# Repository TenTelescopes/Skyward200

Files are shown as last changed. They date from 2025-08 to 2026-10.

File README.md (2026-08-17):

# Skyward200

These designs are licensed under the [Creative Commons Attribution–NonCommercial 4.0 International License](https://creativecommons.org/licenses/by-nc/4.0/).

You are free to:
- Download, modify, and use for personal, non-commercial purposes.
- Share adaptations with credit to **Ten Telescopes**.

You may **not**:
- Sell these designs.
- Sell physical products made from these designs without written permission.

For commercial inquiries, contact: admin@tentelescopes.com

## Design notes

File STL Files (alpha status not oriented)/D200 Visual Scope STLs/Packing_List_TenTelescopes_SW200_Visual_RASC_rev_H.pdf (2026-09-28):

## Ten Telescopes – Skyward 200 Visual Kit Packing Checklist (Young Galileo Style)

2026 September Packed by: | | Date:
| Telescope Number: | Telescope Colours:
☐ | Extrusions | 3030 Aluminum Extrusions 673mm | 4
☐ | OTA Misc | 3mm x 20mm Dowel Pin | 3
☐ | OTA Misc | 10mm x 3mm Round Magnets | 6
☐ | OTA Misc | 3M Outdoor Mounting Tape 15 inches | 1
☐ | OTA Misc | White Gloves | 2
☐ | OTA Misc | Spider Spring | 1
☐ | OTA Nuts and Threaded Inserts | M3 Heat Insert OD5 L6 | 2
☐ | OTA Nuts and Threaded Inserts | M4 Nut | 4
☐ | OTA Nuts and Threaded Inserts | M5 3030 Tnut | 16
☐ | OTA Nuts and Threaded Inserts | M5 Heat Insert OD8L9 | 28
☐ | OTA Printed Parts | 80mm Fan Cover | 1
☐ | OTA Printed Parts | 200mm Dew Shield | 1
☐ | OTA Printed Parts | 200mm Dust Cap Plug | 4
☐ | OTA Printed Parts | 200mm Main Dust Cap | 1
☐ | OTA Printed Parts | 200mm Mid Truss | 2
☐ | OTA Printed Parts | 200mm Mirror Cell | 1
☐ | OTA Printed Parts | 200mm Mirror Cell Cap | 1
☐ | OTA Printed Parts | 200mm Mirror Cell Housing w Extra Deadweigh | 1
☐ | OTA Printed Parts | 200mm Mirror Cell TPU Shear Puck | 3
☐ | OTA Printed Parts | 200mm Mirror Retaining Ring | 1
☐ | OTA Printed Parts | 200mm Round Baffle for Visual | 2
☐ | OTA Printed Parts | 200mm Secondary Ball | 1
☐ | OTA Printed Parts | 200mm Secondary Mirror Holder Socket 70mm | 1
☐ | OTA Printed Parts | 200mm Slide-In Spider | 1
☐ | OTA Printed Parts | 200mm Spider Housing | 1
☐ | OTA Printed Parts | 200mm Spider Rotation Collar | 1
☐ | OTA Printed Parts | 200mm Upper Baffle | 1
☐ | OTA Screws | M3 x 12mm SHCS (black if possible) | 5
☐ | OTA Screws | M4 x 35mm BHCS | 4
☐ | OTA Screws | M5 x 12mm BHCS | 16
☐ | OTA Screws | M5 x 20mm Knob | 3
☐ | OTA Screws | M5 x 35mm BHCS | 14
☐ | OTA Screws | M5 x 35mm Knob | 3
☐ | OTA Screws | M5 x 60mm HCS | 3
☐ | OTA Screws | M5 x 75mm HCS | 1
Packed | Category | Part

Required
Qty

Packed
Qty

### Extrusions

### OTA Misc

### OTA Nuts and Threaded Inserts

### OTA Printed Parts

### OTA Screws

### Optical Mirrors

### Visual Tripod/Mount Misc

### Visual Tripod/Mount Nuts & Threaded Inserts

### Visual Tripod/Mount Printed Parts

### Visual Tripod/Mount Screws

### 2 inch Focuser Misc

### 2 inch Focuser Nuts & Threaded Inserts

☐ | Optical Mirrors | 70mm Secondary Mirror | 1
☐ | Optical Mirrors | AD048 8" F/4 Primary Mirror | 1
☐ | Visual Tripod/Mount Misc | 8 inch Bungie Cord | 3
☐ | Visual Tripod/Mount Misc | Teflon Pad 1/2" x 1" | 4
☐ | Visual Tripod/Mount Misc | Teflon Pad 1" x 1" | 3
☐ | Visual Tripod/Mount Nuts and Threaded Inserts | M3 Heat Insert OD5L6 | 6
☐ | Visual Tripod/Mount Nuts and Threaded Inserts | M5 Heat Insert OD8L9 | 22
☐ | Visual Tripod/Mount Nuts and Threaded Inserts | M5 Standard Nut | 1
☐ | Visual Tripod/Mount Nuts and Threaded Inserts | M6 Wingnut | 3
☐ | Visual Tripod/Mount Printed Parts | 200mm Alt Bearing Outer Ring | 2
☐ | Visual Tripod/Mount Printed Parts | 200mm Dead Weight Dock | 1
☐ | Visual Tripod/Mount Printed Parts | 200mm Crossbrace TPU Dock | 3
☐ | Visual Tripod/Mount Printed Parts | 200mm Core Insert TEN | 2
☐ | Visual Tripod/Mount Printed Parts | 200mm Tripod Cross Brace Bracket | 3
☐ | Visual Tripod/Mount Printed Parts | 200mm Tripod Cross Brace Pull Tab | 3
☐ | Visual Tripod/Mount Printed Parts | 200mm Maple Bearing Core | 2
☐ | Visual Tripod/Mount Printed Parts | 200mm Rocker Box Base | 1
☐ | Visual Tripod/Mount Printed Parts | 200mm Rocker Box Cross Brace | 1
☐ | Visual Tripod/Mount Printed Parts | 200mm Rocker Box Extension Left | 1
☐ | Visual Tripod/Mount Printed Parts | 200mm Rocker Box Extension Right | 1
☐ | Visual Tripod/Mount Printed Parts | 200mm Tripod Apex w Docks | 1
☐ | Visual Tripod/Mount Printed Parts | 200mm Tripod Foot | 3
☐ | Visual Tripod/Mount Printed Parts | 200mm Truss Rocker Box Upright Left | 1
☐ | Visual Tripod/Mount Printed Parts | 200mm Truss Rocker Box Upright Right | 1
☐ | Visual Tripod/Mount Screws | M3 x 8 SHCS | 6
☐ | Visual Tripod/Mount Screws | M5 x 20mm BHCS | 2
☐ | Visual Tripod/Mount Screws | M5 x 25mm BHCS | 18
☐ | Visual Tripod/Mount Screws | M5 x 30mm BHCS | 4
☐ | Visual Tripod/Mount Screws | M5 x 75 SHCS | 1
☐ | Visual Tripod/Mount Screws | M6 x 120 SHCS | 3
☐ | Visual Tripod/Mount Screws | Self Tapping Screw | 9
☐ | 2 inch Focuser Misc | 3mm x 16mm Dowel Pin | 6
☐ | 2 inch Focuser Misc | 4mm Stainless Rod x 110mm | 1
☐ | 2 inch Focuser Misc | 6mm x 3mm Round Magnet | 2
☐ | 2 inch Focuser Misc | 10mm x 3mm Round Magnet | 3
☐ | 2 inch Focuser Misc | Half PTFE Tube 4mm ID, 6mm OD, 18mm Long | 1
☐ | 2 inch Focuser Misc | MGN12H Bearing Block w 100mm Rail | 2
☐ | 2 inch Focuser Misc | MGN12H Bare Rail 100mm | 1
☐ | 2 inch Focuser Nuts & Threaded Inserts | M3 Heated Insert D5 L6 | 10
☐ | 2 inch Focuser Nuts & Threaded Inserts | M3 Nut | 2

☐ | 2 inch Focuser Nuts & Threaded Inserts | M5 Nyloc Nut | 5
☐ | 2 inch Focuser Nuts & Threaded Inserts | M5 Heated Insert OD8 L9 | 3
☐ | 3 inch Focuser Printed Parts | 2"to1.25" Adapter | 1
☐ | 2 inch Focuser Printed Parts | Coarse Focus Housing | 1
☐ | 2 inch Focuser Printed Parts | Coarse Focus Knob | 1
☐ | 2 inch Focuser Printed Parts | Fine Focus Knob | 1
☐ | 2 inch Focuser Printed Parts | Fine Focus Right Angle Mount | 1
☐ | 2 inch Focuser Printed Parts | Focuser Body | 1
☐ | 2 inch Focuser Printed Parts | Focuser Inside Drawtube | 1
☐ | 2 inch Focuser Printed Parts | Focuser Outside Drawtube | 1
☐ | 2 inch Focuser Printed Parts | Planetary Gearset 1 | 1
☐ | 2 inch Focuser Printed Parts | Planetary Gearset 2 | 1
☐ | 2 inch Focuser Printed Parts | Plunger | 1
☐ | 2 inch Focuser Printed Parts | Transfer Plate | 1
☐ | 2 inch Focuser Screws | M3 x 8mm SHCS or BHCS | 20
☐ | 2 inch Focuser Screws | M3 x 14mm SHCS | 6
☐ | 2 inch Focuser Screws | M3 x 18mm SHCS | 1
☐ | 2 inch Focuser Screws | M3 x 20mm Countersinking Hex Screw | 3
☐ | 2 inch Focuser Screws | M3 x 25mm Thumb Screw | 4
☐ | 2 inch Focuser Screws | M5 x 75mm SHCS or BHCS | 5
☐ | 2 inch Focuser Screws | M5 Grub Screw | 3
☐ | Accessories Nuts & Threaded Inserts | M5 Heated Insert OD8 L9 | 4
☐ | Accessories Screws | M5 x 12mm BHCS | 4
☐ | Accessories Misc | 23mm Eyepiece | 1
☐ | Accessories Misc | 1.25" Laser Collimater | 1
☐ | Accessories Misc | Nex YZ | 1
☐ | Accessories Misc | Red Dot Finder | 1
☐ | Accessories Misc | Solar Filter Film | 1
☐ | Accessories Misc | Solar Filter Film | 1
☐ | Accessories Misc | Phone Dock Spring | 1
☐ | Accessories Printed Parts | 200mm Phone Dock Bridge Mount | 1
☐ | Accessories Printed Parts | 200mm Solar Filter Frame | 1
☐ | Accessories Printed Parts | 200mm Solar Filter Retaining Ring | 1
☐ | Accessories Printed Parts | 200mm Solar Filter TPU Gasket | 1
☐ | Accessories Printed Parts | Phone Dock Mounted Bracket | 1
☐ | Accessories Printed Parts | Phone Dock Screw | 1
☐ | Accessories Printed Parts | Phone Dock Threaded Bracket | 1
☐ | Tripod parts from Hardware Store | 15" length of 1" I.D. PVC electrical conduit | 3 | 0
☐ | Tripod parts from Hardware Store | 36" length of 2" I.D. ABS plumbing pipe | 3 | 0

### 2 inch Focuser Printed Parts

### 2 inch Focuser Screws

### Accessories Nuts & Threaded Inserts

### Accessories Screws

### Accessories Misc

### Accessories Printed Parts

### Supplied by User

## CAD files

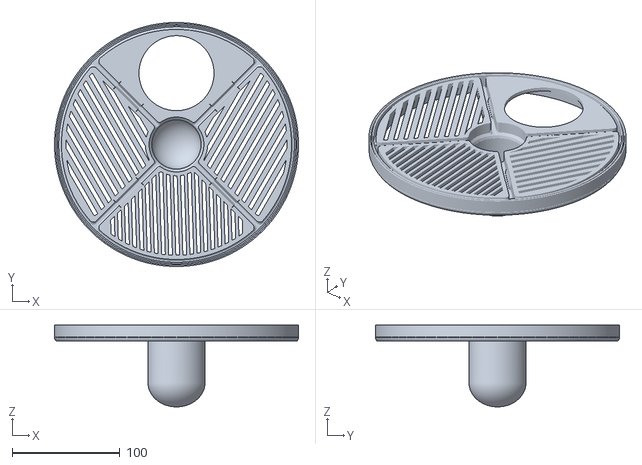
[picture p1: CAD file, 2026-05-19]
STL Files (alpha status not oriented)/D200 Visual Scope STLs/OTA Printed Parts/200mm Main Dust Cap.stl
226.7 x 226.7 x 76.0

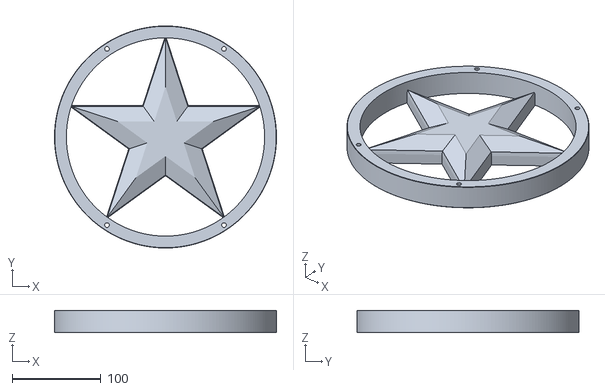
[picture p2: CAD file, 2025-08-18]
STL Files (alpha status not oriented)/Bearing Core Design Options/D203 Superstar Bearing Core x2.stl
250.0 x 250.0 x 25.0

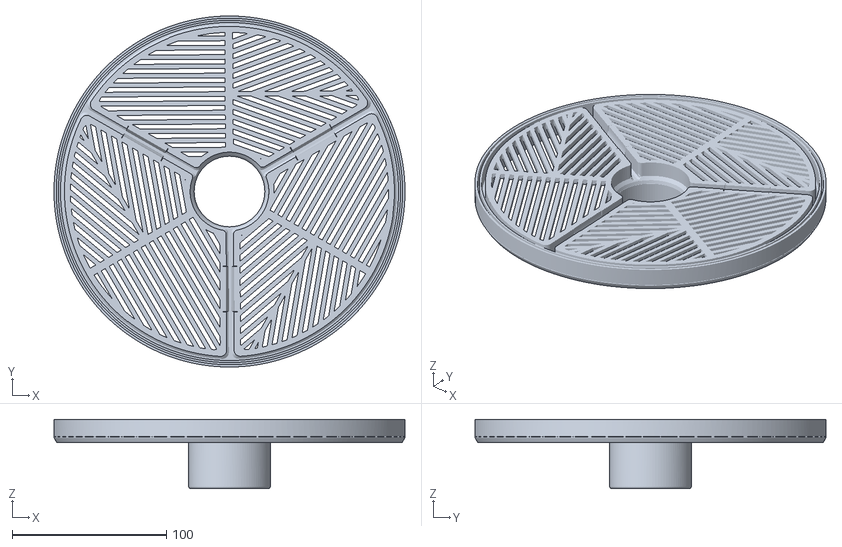
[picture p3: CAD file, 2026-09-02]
STL Files (alpha status not oriented)/D200 Astrograph Scope STLs/200mm Astrograph Tri Bhatinov Mask.stl
227.4 x 227.4 x 45.0

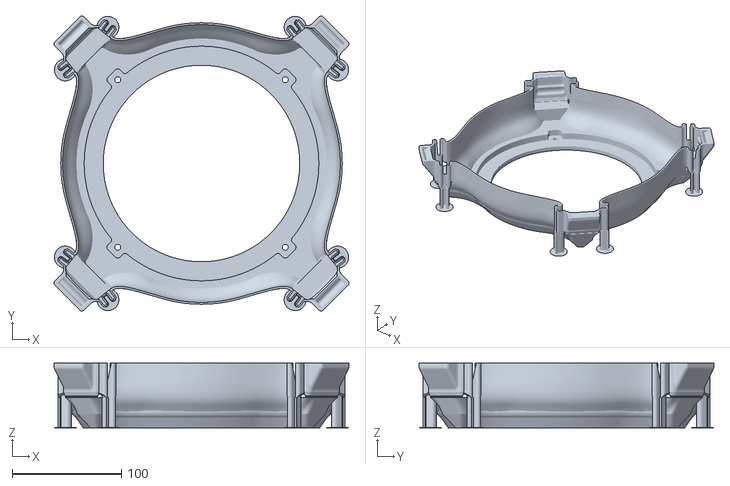
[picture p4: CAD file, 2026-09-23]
STL Files (alpha status not oriented)/D200 Visual Scope STLs/Accessories Printed Parts/200mm Solar Filter Frame.stl
270.3 x 270.3 x 59.5

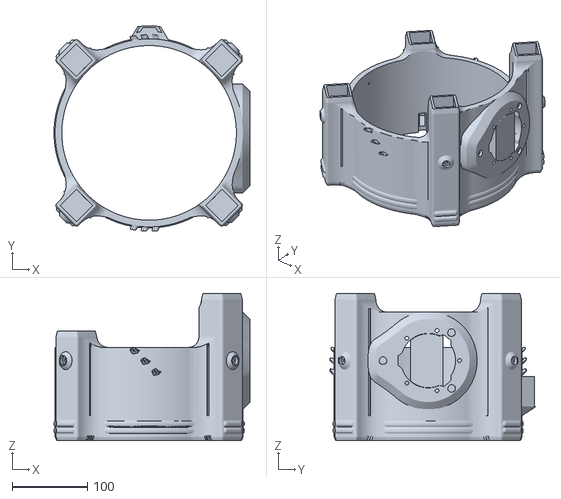
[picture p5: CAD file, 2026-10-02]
STL Files (alpha status not oriented)/D200 Visual Scope STLs/OTA Printed Parts/200mm Spider Housing.stl
261.3 x 273.4 x 196.0

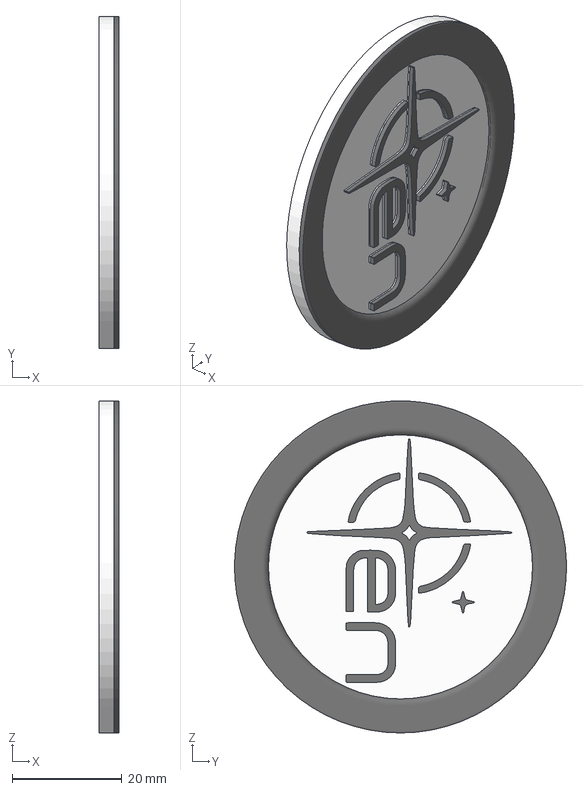
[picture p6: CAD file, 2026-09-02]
STL Files (alpha status not oriented)/D200 Visual Scope STLs/Visual Tripod-Mount Printed Parts/200mm Bearing Core Ten Badge.3mf
3.70 x 60.5 x 60.5 mm
Main Body (2)
Maple Bearing Core (1) (1) (1) (1)

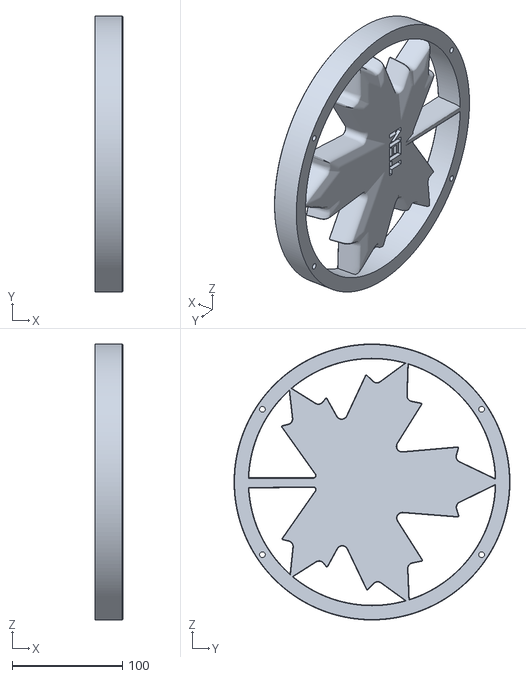
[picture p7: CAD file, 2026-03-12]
STL Files (alpha status not oriented)/D200 Visual Scope STLs/Visual Tripod-Mount Printed Parts/Optional/200mm Maple Bearing Core x 2.stl
25.0 x 250.0 x 250.0

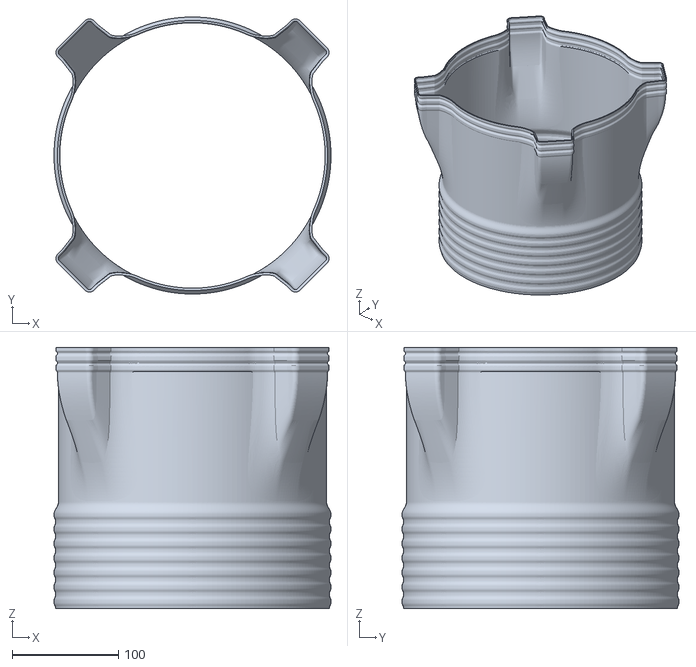
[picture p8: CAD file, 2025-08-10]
STL Files (alpha status not oriented)/D203 Dew Shield Corrugated.stl
261.0 x 261.0 x 246.4

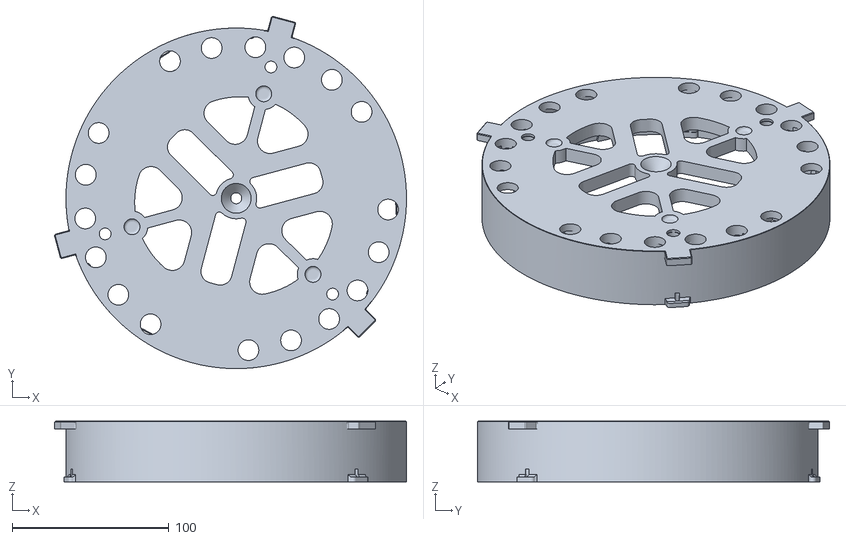
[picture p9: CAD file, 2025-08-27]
STL Files (alpha status not oriented)/Mirror Cell for 8 inch Mirrors (203mm)/D203 Mirror Cell with New Centering Spring Fingers.stl
224.5 x 224.6 x 38.6

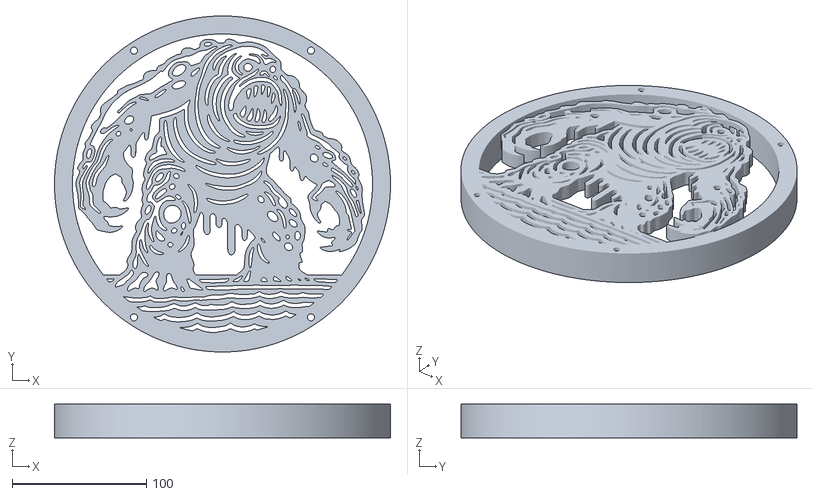
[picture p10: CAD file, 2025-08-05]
STL Files (alpha status not oriented)/Bearing Core Design Options/D203 Swamp Monster Bearing Core Left.stl
250.0 x 250.0 x 25.0

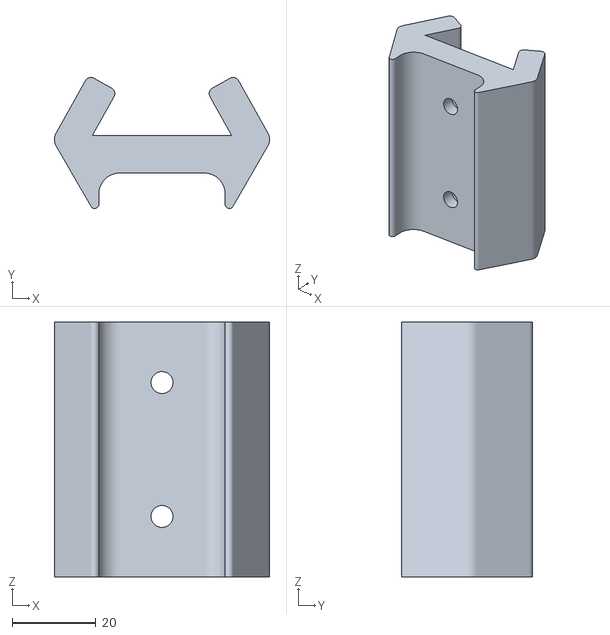
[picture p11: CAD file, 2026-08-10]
STL Files (alpha status not oriented)/D200 Astrograph Scope STLs/200mm Astrograph Large Guidescope Computer Mounts.stl
51.5 x 31.3 x 61.0

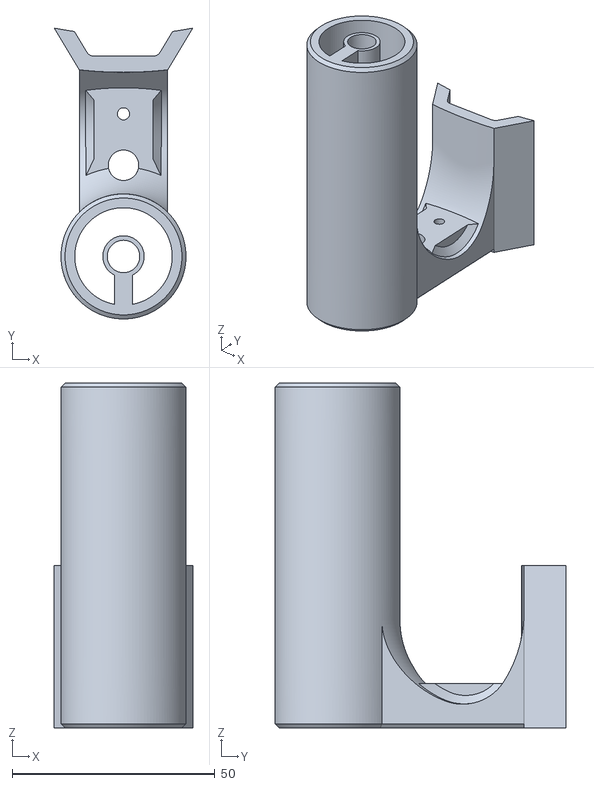
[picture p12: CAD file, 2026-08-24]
STL Files (alpha status not oriented)/D200 Visual Scope STLs/Accessories Printed Parts/Solar Finder Part 1.stl
34.2 x 71.7 x 85.0

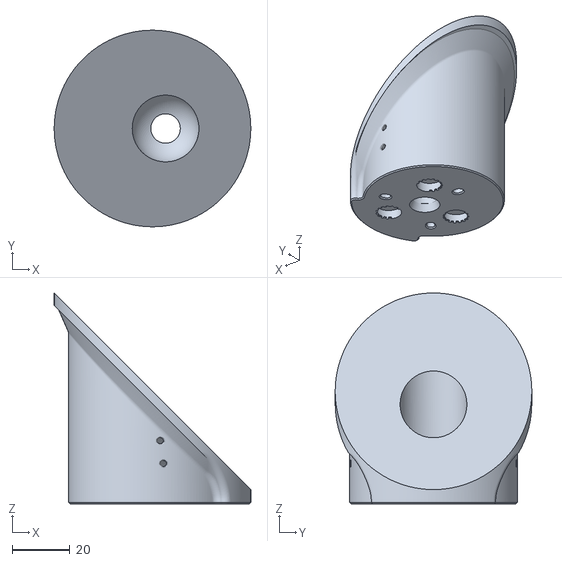
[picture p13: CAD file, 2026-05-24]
STL Files (alpha status not oriented)/D200 Visual Scope STLs/OTA Printed Parts/200mm Secondary Mirror Holder Socket 70mm.stl
68.0 x 68.0 x 73.0

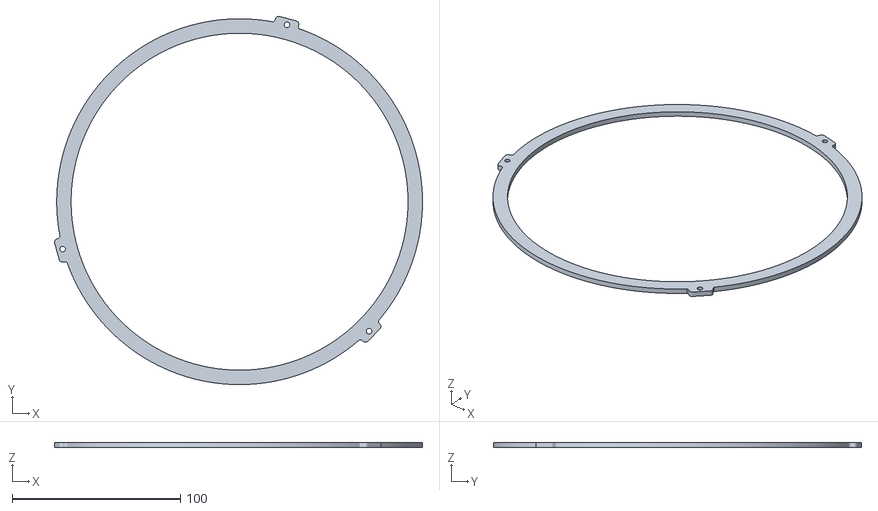
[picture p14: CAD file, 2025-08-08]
STL Files (alpha status not oriented)/Mirror Cell for 8 inch Mirrors (203mm)/D203 Retaining Ring.stl
218.5 x 218.6 x 3.00

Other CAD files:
STL Files (alpha status not oriented)/D200 Visual Scope STLs/Visual Tripod-Mount Printed Parts/200mm Maple Bearing Core.stl
STL Files (alpha status not oriented)/Bearing Core Design Options/D203 Swamp Monster Bearing Core Right.stl
STL Files (alpha status not oriented)/D200 Astrograph Scope STLs/200mm Astrograph Dovetail.stl
STL Files (alpha status not oriented)/D200 Visual Scope STLs/Accessories Printed Parts/Solar Finder Part 2.stl
STL Files (alpha status not oriented)/D200 Astrograph Scope STLs/200mm Astrograph 3 Vane Spider.stl
STL Files (alpha status not oriented)/D200 Astrograph Scope STLs/200mm Astrograph CrossStruts.stl
STL Files (alpha status not oriented)/D200 Astrograph Scope STLs/200mm Astrograph Handle.stl
STL Files (alpha status not oriented)/D200 Astrograph Scope STLs/200mm Astrograph Mid Truss x 2.stl
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

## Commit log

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2025-07-09 Create D203 Secondary Mirror Holder Socket w 60mm astrograph offset.stl
    [D203 Secondary Mirror Holder Socket w 60mm astrograph offset.stl]
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2025-07-14 Update D203 Astrograph Dovetail Mount.stl
    [D203 Astrograph Dovetail Mount.stl]
2025-07-25 Update Guidescope Computer Mounts Large Guidescope.stl
    [Guidescope Computer Mounts Large Guidescope.stl]
2025-07-28 Create D203 Rocker Box Base.stl
    [D203 Rocker Box Base.stl]
2025-07-28 Update D203 Rocker Box Crosspiece.stl
    [D203 Rocker Box Crosspiece.stl]
2025-07-31 Update D203 Mid Truss x 2.stl
    [D203 Mid Truss x 2.stl]
2025-08-01 Reworking Alpha Parts
    [D203 Dew Shield.stl, D203 Rocker Box Base.stl]
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2025-08-02 Update D203 Mirror Cell Cap.stl
    [D203 Mirror Cell Cap.stl]
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2025-08-04 Update D203 Rocker Box Base.stl
    [D203 Rocker Box Base.stl]
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2025-08-10 Create D203 Dew Shield Corrugated.stl
    [D203 Dew Shield Corrugated.stl]
2025-08-10 Update D203 Dew Shield Corrugated.stl
    [D203 Dew Shield Corrugated.stl]
2025-08-11 Update D203 2 Colour Spider Assembly.3mf
    [D203 2 Colour Spider Assembly.3mf]
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2025-08-11 Folder labeled as Alpha because that's where we are
    [D203 2 Colour Spider Assembly.3mf, D203 Astrograph Dovetail Mount.stl, D203 Astrograph Handle.stl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]
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2025-08-11 Create D203 Slide-in Spider.stl
    [D203 Slide-in Spider.stl]
2025-08-12 Update D203 Upper Baffle.stl
    [D203 Upper Baffle.stl]
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2025-08-13 Better Slide in Spider
    [D203 2 Colour Spider Assembly.3mf, D203 Slide-in Spider.stl]
2025-08-15 More refinements to finish
    [D203 2 Colour Spider Assembly.3mf, D203 Astrograph Dovetail Mount.stl, D203 Astrograph Handle.stl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]
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2025-08-15 Create D203 Mirror Cell with New Centering Spring Fingers.stl
    [D203 Mirror Cell with New Centering Spring Fingers.stl]
2025-08-16 Mirror Cell Updates and other bits
    [200mm Mirror Cell (not 8 inch).stl, 200mm Mirror Cell w Centering Springs (not 203).stl, 200mm Retaining Ring (not 203).stl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]
2025-08-16 refinements to truss uprights for printability
    [D203 Truss Rocker Upright Left.stl, D203 Truss Rocker Upright Right.stl]
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2025-08-18 Create D203 Superstar Bearing Core x2.stl
    [D203 Superstar Bearing Core x2.stl]
2025-08-18 Update D203 Visual Alt Bearing Outer Ring x 2.stl
    [D203 Visual Alt Bearing Outer Ring x 2.stl]
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2025-08-20 Update D203 Dead Weight.stl
    [D203 Dead Weight.stl]
2025-08-20 Create D203 Fan Cover.stl
    [D203 Fan Cover.stl]
2025-08-27 Kendrick Rope Heater Updates
    [D203 Mirror Cell Cap for Kendrick Rope.stl, D203 Mirror Cell with New Centering Spring Fingers.stl]
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2025-08-29 refinements to secondary rotation control
    [D203c 70mm Secondary Holder with Rotation Control.stl, D203c Spider Rotation Collar.stl]
2025-09-29 Experimental Spider Assembly Upgrades
    [D203c 70mm Secondary Holder with Rotation Control.stl, D203c Spider Housing for 3DP Focuser and Slide in Spider.stl, D203c Spider Rotation Collar.stl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]
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2025-10-20 Update 200mm Mirror Cell w Centering Springs (not 203).stl
    [200mm Mirror Cell w Centering Springs (not 203).stl]
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2025-12-21 New Style SW200 Updates
    [D203 Dew Shield Thicker.stl, D203 Dew Shield.stl, D203 Mirror Cell Cap for Kendrick Rope.stl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]
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2026-01-04 Update D203e Spider Housing for 3DP Focuser and Slide in Spider.stl
    [D203e Spider Housing for 3DP Focuser and Slide in Spider.stl]
2026-03-12 Lots and Lots of Changes
    [200mm Mirror Cell w Centering Springs (not 203).stl, 200mm Retaining Ring (not 203).stl, 200mm Retaining Ring (not 8 inch).stl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]
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2026-04-20 Update 200mm Tripod Apex w Docks.stl
    [200mm Tripod Apex w Docks.stl]
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2026-04-27 Update 200mm Tripod Crossbrace Pull Tab x 3.stl
    [200mm Tripod Crossbrace Pull Tab x 3.stl]
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2026-04-27 Update 200mm Solar Filter Frame.stl
    [200mm Solar Filter Frame.stl]
2026-05-01 Update 200mm Mirror Cell Body w Extra Deadweight.stl
    [200mm Mirror Cell Body w Extra Deadweight.stl]
2026-05-06 Update 200mm Spider Housing.stl
    [200mm Spider Housing.stl]
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2026-05-16 Naming fix
    [200mm Mirror Cell Housing w Extra Deadweight.stl]
2026-05-23 Update 200mm Slide in Spider.stl
    [200mm Slide in Spider.stl]
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2026-05-24 Update 200mm Rocker Box Base.stl
    [200mm Rocker Box Base.stl]
2026-05-24 Update 200mm 70mm Secondary Holder Socket.stl
    [200mm 70mm Secondary Holder Socket.stl]
2026-06-08 General Reorganization of Files
    [200mm 70mm Secondary Holder Socket.stl, 200mm 80mm Fan Cover.stl, 200mm Astrograph 3 Vane Spider.stl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]
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2026-06-15 Mirror Cell with Extra Side Support
    [200mm Rocker Box Base.3mf]
2026-07-08 Update Astrohopper Phone Base.3mf
    [Astrohopper Phone Base.3mf]
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2026-08-17 Updated Apex for TPU Docks
    [200mm Tripod Apex w Docks.stl, TPU Crossbrace Docks x3.stl]
2026-08-18 New Apex Docking Scheme
    [200mm Tripod Apex w Docks.stl, TPU Crossbrace Docks x3.stl]
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2026-08-25 Create 200mm Two Colour Ten Logo Maple Bearing Core.3mf
    [200mm Two Colour Ten Logo Maple Bearing Core.3mf]
2026-08-26 Update 200mm Two Colour Ten Logo Maple Bearing Core.3mf
    [200mm Two Colour Ten Logo Maple Bearing Core.3mf]
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
